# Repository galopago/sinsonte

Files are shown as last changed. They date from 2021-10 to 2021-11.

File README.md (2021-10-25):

# SOUND PLAYER BASED ON RPI PICO

Sound player based on Raspberry Rpi Pico. Sound data are stored in onboard memory. Very few external (easy to find & solder) components required. The project was designed to be in sleep mode for a very long time powered by batteries. Can be used for musical wall clocks, talking dolls, toys, etc.

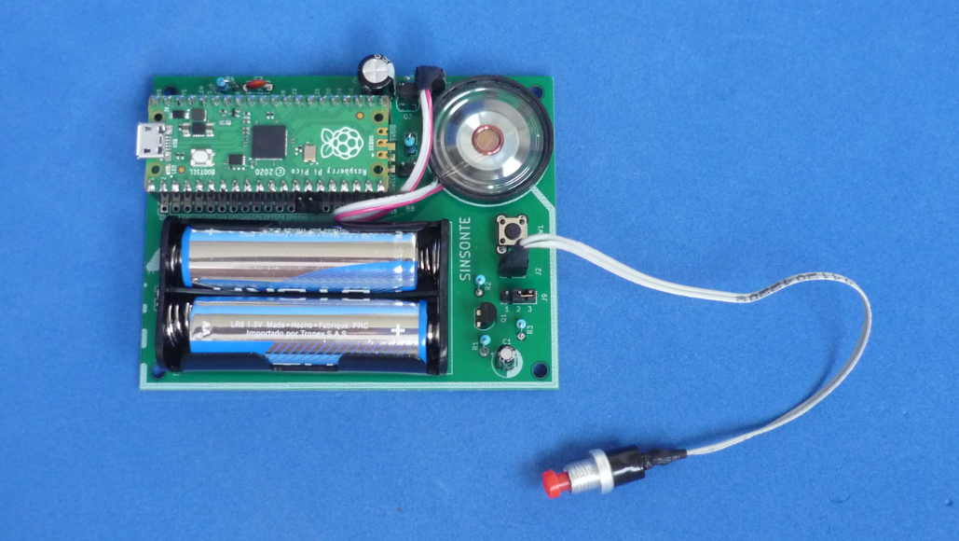
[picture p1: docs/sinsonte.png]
BOARD


Printed circuit board with all components soldered.

Also read this in other languages: [Espanol](/docs/README.es.md)

## Working principle

The circuit ([see schematic](/docs/schematic.pdf)) has been designed to stay most of the time in silence powered by 2 AA batteries, like musical wall clocks or talking toys. In the best scenario, Rpi Pico in in deep sleep mode, will drain approx 1.3 mAh from the batteries. A pair of AA batteries in series have around 2000 mAh of juice, just in standby they will last only for two months. Unacceptable!.

An external circuit was added to totally power off Rpi Pico via 3V3_EN pin. Draining just only 70 uAh, which translates to 3 years of standby. Much better!

The circuit work in the following manner: In standby mode, a capacitor with a large resistor holds the conduction voltage of a MOSFET which is in charge of tying 3V3_EN to ground, powering off the board completely. To play a sound, click briefly on the push button which discharges the capacitor and stops conduction of the MOSFET. Now 3V3_EN pin is tied to V+ via its internal pull up, powering on the Rpi Pico Board. Once powered on and program booted, it keeps the capacitor discharged via a GPIO while sound is played. When the sound ends, the RPI Pico puts the GPIO in high impedance state, so the capacitor charges again and Rpi Powers off until the next click on the button!

There are many stored sounds in the Rpi Pico, and they are played in sequence. To know which sound needs to be played in the next click, some data needs to be preserved between power offs, that data is stored in the internal flash memory. Be careful modifying the program to keep flash writes to a minimum.

The program was written using the Rpi Pico SDK and more or less the same functionality also in CircuitPython too!

## Directory structure

Hardware folder contains schematic and printed circuit board.
* /hardware/ folder contains KiCad V5.1 project
* /hardware/gerber folder contains ready to manufacture files.
* /hardware/modules folder contains additional footprints needed to edit printed circuit board.
* /hardware/library folder contains additional symbols needed to edit schematic.

Software folder contains program source code.
* /software/sdk folder contains C source code for multiple apps develped with the Raspberry **Pi Pico SDK**.
* /software/sdk/clock/build folder will contain downloadable binaries once compiled.
* /software/sdk/_utils folder contain additional python scripts.
* /software/sdk/_uf2_binaries folder contains compiled programs ready for download to the Rpi Pico.
* /software/sdk/_sounds folder contains sound files source in form of C arrays[].

* /software/cp folder contains Python source code for multiple apps develped with **CircuitPython**.
* /software/cp/_sounds folder contains sound files source in .mp3 format
* /software/cp/_utils folder contains contains binary files

Docs folder contains additional info files

# C/C++ SDK
## How to use this repository

This is a very brief guide how to install Rpi Pico SDK on Linux (Ubuntu!). For more info please visit [official repo](https://github.com/raspberrypi/pico-sdk)
~~~
sudo apt install cmake gcc-arm-none-eabi libnewlib-arm-none-eabi build-essential
git clone -b master https://github.com/raspberrypi/pico-sdk.git
cd pico-sdk
git submodule update --init
~~~
Add the line below to .bashrc file, and then restart session to allow changes to take effect.
~~~
export PICO_SDK_PATH={sdk path}/pico-sdk
~~~
Clone project repository
~~~
git clone https://github.com/galopago/SINSONTE.git
~~~
* Modify /SINSONTE/software/sdk/clock/CMakeLists.txt file change Rpi Pico SDK paths with your own installation paths.
* Delete /SINSONTE/software/sdk/clock/build/CMakeCache.txt file
* Delete /SINSONTE/software/sdk/clock/build/elf2uf2/CMakeCache.txt file

Using the command line terminal go to the folder /SINSONTE/software/sdk/clock/build
~~~
cd software/sdk/clock/build
~~~
Generate makefiles
~~~
cmake ..
~~~
And finally compile:
~~~
make clean
make all
~~~
(.uf2) downloadable compiled file lies in /SINSONTE/software/sdk/clock/build

## How to change sound files

The sample program shown here, plays 12 different sound files sequentially. If you want to change one or all of them, the following rules must be taken into account:

* Max sound storage capacity is 24 seconds total (~2 seconds per file * 12 files = ~24 seconds)
* Sound files have to be in .WAV mono 16 bit @ 44100 hz before being processed by the script which converts them into C array[]

Look for **wav2c.py** script in /SINSONTE/software/sdk/_utils/ folder to convert your own sounds.

This script need two parameters: input sound file name (.wav) and output file name (.h). The files have to be named 1.h to 12.h. Here is an example:

~~~
python3 wav2c.py example.wav 5.h
~~~

The generated file (5.h) needs to be put in /SINSONTE/software/sdk/clock folder and then recompile!

# CircuitPython
## How to use this repository
Clone project repository
~~~
git clone https://github.com/galopago/SINSONTE.git
~~~
* Put Rpi Pico in programming mode and then plug into a PC
* To start fresh, download to the Rpi Pico the file **flash_nuke.uf2** located in /SINSONTE/software/cp/_utils
* Put Rpi Pico in programming mode again and then plug into a PC
* Install CircuitPython runtime downloading the file **adafruit-circuitpython-raspberry_pi_pico-en_US-6.3.0.uf2** located in /SINSONTE/software/cp/_utils
* Once CircuitPython is installed, download to the Rpi Pico **code.py** and the sound files (1.mp3 to 12.mp3) located in /SINSONTE/software/cp/clock folder

## How to change sound files
Download to the Rpi Pico your own .mp3 file, it needs to be named 1.mp3 to 12.mp3

## License
This is an Open Source project and is licensed under [MIT License](https://spdx.org/licenses/MIT.html)

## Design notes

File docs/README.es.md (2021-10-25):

# REPRODUCTOR DE SONIDO BASADO EN RPI PICO

Reproductor de sonido basado en Raspberry Rpi Pico. Almacena los datos de sonido en la memoria interna. Requiere muy pocos componentes externos faciles de conseguir y de ensamblar. Fue diseñado con el objetivo de permanecer en modo espera durante muy largo tiempo alimentado por baterias. Puede usarse en relojes de pared musicales, como voz para alguna muñeca o juguete, etc.

TARJETA

Tarjeta de circuito impreso con todos los componentes montados.

Tambien puede leer esto otros idiomas: [English](../README.md)

## Funcionamiento general

El circuito ([ver esquematico](../docs/schematic.pdf)) se ha diseñado para que permanezca la mayoria del tiempo en silencio y alimentado por 2 baterias AA, como es el caso de los relojes musicales o juguetes que hablan. En el mejor de los casos, el Rpi Pico en su menor consumo (usando funciones de sueño profundo), drenara aproximadamente 1.3 mAh de las baterias. Como un par de baterias AA tiene una capacidad aproximada de 2000 mAh, solamente en modo espera tendrian una duracion aproximada de dos meses. Inaceptable!.

Se adiciono un circuito externo que mantiene totalmente apagado el Rpi Pico usando el pin 3V3_EN de esta forma solo consumira aproximadamente unos 70 uA, lo que se traduce en unos 3 años en modo espera. Mucho mejor!

El sistema funciona de la siguiente manera: En modo reposo, un condensador mediante una resistencia grande mantienen el voltaje de conduccion de un mosfet que es el encargado de poner a tierra la señal 3V3_EN, apagando totalmente la tarjeta. Para reproducir un sonido se debera pulsar brevemente un interruptor. Este interruptor descarga el condensador rapidamente, apagando el mosfet y haciendo que la señal 3V3_EN quede a V+ mediante su resistencia interna, haciendo que el Rpi Pico se encienda. Una vez encendido el Rpi Pico, este mantiene descargado el condensador mediante un GPIO durante la reproduccion del sonido. Al finalizar la reproduccion, el GPIO se pone en alta impedancia haciendo que el circuito externo cargue de nuevo el condensador y apague el Rpi Pico hasta la proxima pulsacion!

En el Rpi Pico se almacenan varios sonidos, y estos se reproducen en secuencia con cada pulsacion del interruptor. Para poder guardar cual sonido se repoducira en la siguiente pulsacion, se hace uso de la memoria flash interna, por lo que se debera analizar con cuidado la aplicacion final del circuito para evitar desgastes rapidos de la flash.

El programa fue escrito usando el Rpi Pico SDK y se porto mas o menos la misma funcionalidad a CircuitPython tambien!

## Estructura de directorios

El directorio hardware contiene el esquematico y circuito impreso.
* El directorio /hardware/ contiene el proyecto completo en KiCad V5.1.
* El directorio /hardware/gerber contiene los archivos de fabricacion del circuito impreso.
* El directorio /hardware/modules contiene footprints adicionales necesarios para poder editar el circuito impreso.
* El directorio /hardware/library contiene simbolos adicionales necesarios para poder editar el esquematico.

El directorio software contiene el codigo fuente del programa.
* El directorio /software/sdk contiene el codigo fuente en C de varias apps desarrolladas en el **Raspberry Pi Pico SDK**.
* El directorio /software/sdk/clock/build contendra los archivos cuando se compila el codigo.
* El directorio /software/sdk/_utils contiene scripts complementarios en python.
* El directorio /software/sdk/_uf2_binaries contiene archivos compilados listos para descargar al Rpi Pico.
* El directorio /software/sdk/_sounds contiene archivos de sonido en forma de arrays[] de C.

* El directorio /software/cp contiene el codigo fuente de en Python de varias apps desarrolladas en el **CircuitPython**.
* El directorio /software/cp/_sounds contiene archivos de sonido en formato mp3.
* El directorio /software/cp/_utils contiene archivos binarios.

El directorio docs contiene archivos adicionales

# C/C++ SDK
## Como usar este repositorio

Esta es una descripcion breve de como instalar el Rpi Pico SDK en Linux (Ubuntu!). Para mayor informacion ir al [repo oficial](https://github.com/raspberrypi/pico-sdk)
~~~
sudo apt install cmake gcc-arm-none-eabi libnewlib-arm-none-eabi build-essential
git clone -b master https://github.com/raspberrypi/pico-sdk.git
cd pico-sdk
git submodule update --init
~~~
Se debera añadir la siguiente linea al archivo .bashrc y despues de hacerlo, reiniciar sesion para que tome efecto
~~~
export PICO_SDK_PATH={ruta sdk}/pico-sdk
~~~
Clonar el repositorio del proyecto
~~~
git clone https://github.com/galopago/SINSONTE.git
~~~
* Modificar el archivo /SINSONTE/software/sdk/clock/CMakeLists.txt cambiando las rutas del SDK Pico por la ruta en que se instalo en su propia computadora.
* Borrar el archivo /SINSONTE/software/sdk/clock/build/CMakeCache.txt
* Borrar el archivo /SINSONTE/software/sdk/clock/build/elf2uf2/CMakeCache.txt

Mediante la interfaz linea de comando acceda al directorio /SINSONTE/software/sdk/clock/build
~~~
cd software/sdk/clock/build
~~~
Crear los makefiles
~~~
cmake ..
~~~
Y finalmente para compilar:
~~~
make clean
make all
~~~
El programa compilado (.uf2) para descargar al Rpi Pico se encontrara en la carpeta /SINSONTE/software/sdk/clock/build

## Como cambiar los archivos de sonido

El programa presentado aqui reproduce 12 diferentes archivos de sonido de forma secuencial. Si se quiere cambiar uno o todos los archivos se debera tener en cuenta lo siguiente:

* La duracion maxima de almacenamiento de la memoria es de 24 segundos (2 segundos por sonido * 12 = 24 segundos)
* Los archivos deberan convertirse a formato .WAV monofonico de 16 bits y a 44100 hz antes de ser procesados por la aplicacion que los convertira en array[] de C.

Una vez se tienen los archivos con las caracteristicas anteriormente mencionadas, se usara la aplicacion **wav2c.py** que se encuentra en la ruta /SINSONTE/software/sdk/_utils

Esta aplicacion recibe dos parameteros: el nombre de arhcivo de entrada (.wav) y nombre de archivo de salida (.h). Los nombres de los archivos convertidos deberan llamarse 1.h a 12.h. Un ejemplo seria el siguiente:

~~~
python3 wav2c.py ejemplo.wav 5.h
~~~

El archivo generado (5.h) debera ponerse en la carpeta /SINSONTE/software/sdk/clock y recompilar el codigo

# CircuitPython
## Como usar este repositorio

Clonar el repositorio del proyecto
~~~
git clone https://github.com/galopago/SINSONTE.git
~~~
* Poner el Rpi Pico en modo programacion y luego conectar a un PC
* Para iniciar con todo limpio, descargar al Rpi Pico el archivo **flash_nuke.uf2** que se encuentra en /SINSONTE/software/cp/_utils
* Poner nuevamente el Rpi Pico en modo programacion y conectar a un PC
* Instalar CircuitPython descargandole el archivo **adafruit-circuitpython-raspberry_pi_pico-en_US-6.3.0.uf2** que se encuentra en /SINSONTE/software/cp/_utils
* Una vez ya se ha instalado CircuitPython, descargar al Rpi Pico el archivo **code.py** y los archivos de sonido (1.mp3 al 12.mp3) que se encuentran en /SINSONTE/software/cp/clock 

## Como cambiar los archivos de sonido
Descargar al Pico sus propios archivos .mp3, estos deben llamarse 1.mp3 al 12.mp3

## Licencia
Este es un proyecto de Software Libre y esta licenciado bajo una licencia [MIT License](https://spdx.org/licenses/MIT.html)

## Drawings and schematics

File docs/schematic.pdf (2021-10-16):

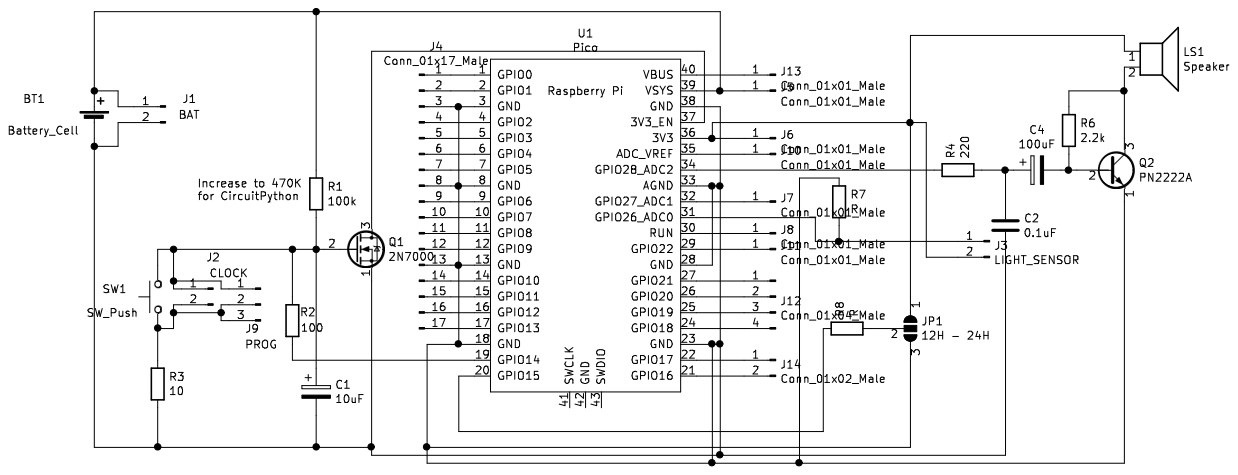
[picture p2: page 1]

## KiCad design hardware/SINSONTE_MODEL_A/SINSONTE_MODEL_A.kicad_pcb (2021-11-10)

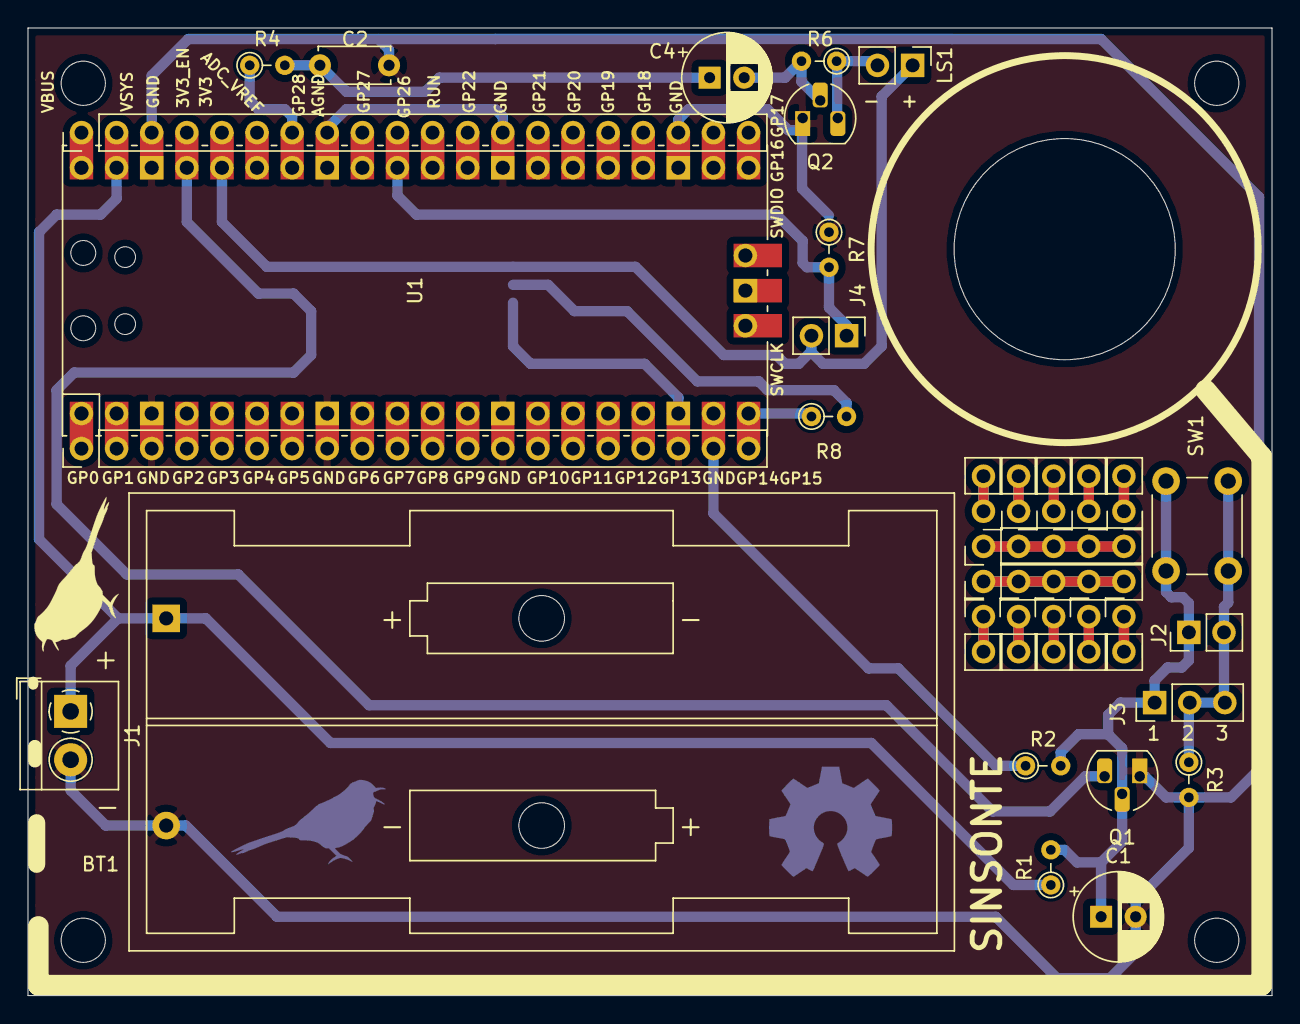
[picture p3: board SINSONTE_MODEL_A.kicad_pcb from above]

Board: 2 copper layers, 90.0 x 70.0 mm, 35 parts (1 on the bottom side), 51 nets.

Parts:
BT1: Battery_Cell; BatteryHolder_Keystone_2462_2xAA
C1: 10uF; CP_Radial_D6.3mm_P2.50mm
C2: 0.1uF; C_Disc_D5.0mm_W2.5mm_P5.00mm
C4: 100uF; CP_Radial_D6.3mm_P2.50mm
J1: BAT; TerminalBlock_4Ucon_1x02_P3.50mm_Horizontal
J2: CLOCK; PinHeader_1x02_P2.54mm_Vertical
J3: PROG; PinHeader_1x03_P2.54mm_Vertical
J4: LIGHT_SENSOR; PinHeader_1x02_P2.54mm_Vertical
J5, J6: Conn_01x20_Male; PinHeader_1x20_P2.54mm_Vertical
J7, J8: Conn_01x05_Male; PinHeader_1x05_P2.54mm_Vertical
J9, J10, J11, J12, J13, J14, J15, J16, J17, J18: Conn_01x02_Male; PinHeader_1x02_P2.54mm_Vertical
JP1: 12H - 24H; SolderJumper-3_P1.3mm_Open_RoundedPad1.0x1.5mm_NumberLabels
LS1: Speaker; PinHeader_1x02_P2.54mm_Vertical
Q1: 2N7000; TO-92_HandSolder
Q2: PN2222A; TO-92_HandSolder
R1: 100k; R_Axial_DIN0204_L3.6mm_D1.6mm_P2.54mm_Vertical
R2: 100; R_Axial_DIN0204_L3.6mm_D1.6mm_P2.54mm_Vertical
R3: 10; R_Axial_DIN0204_L3.6mm_D1.6mm_P2.54mm_Vertical
R4: 220; R_Axial_DIN0204_L3.6mm_D1.6mm_P2.54mm_Vertical
R6: 2.2k; R_Axial_DIN0204_L3.6mm_D1.6mm_P2.54mm_Vertical
R7, R8: R; R_Axial_DIN0204_L3.6mm_D1.6mm_P2.54mm_Vertical
SW1: SW_Push; SW_PUSH_6mm_H4.3mm
U1: Pico; RPi_Pico_SMD_TH

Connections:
unnamed: BT1.1, J1.1, J6.2, R1.1, U1.39
unnamed: BT1.2, C1.2, C2.2, J1.2, J5.3, J5.8, J5.13, J5.18, J6.3, J6.8, J6.13, J6.18, JP1.3, Q1.1, Q2.1, R3.2, R7.1, U1.3, U1.8, U1.13, U1.18, U1.23, U1.28, U1.33, U1.38
unnamed: C1.1, J2.1, J3.1, Q1.2, R1.2, R2.2, SW1.1
unnamed: C2.1, C4.1, R4.2
unnamed: C4.2, Q2.2, R6.2
unnamed: J2.2, J3.2, J3.3, R3.1, SW1.2
unnamed: J4.1, J6.10, R7.2, U1.31
unnamed: J4.2, J6.5, JP1.1, LS1.1, U1.36
unnamed: J5.1, U1.1
unnamed: J5.2, U1.2
unnamed: J5.4, U1.4
unnamed: J5.5, U1.5
unnamed: J5.6, U1.6
unnamed: J5.7, U1.7
unnamed: J5.9, U1.9
unnamed: J5.10, U1.10
unnamed: J5.11, U1.11
unnamed: J5.12, U1.12
unnamed: J5.14, U1.14
unnamed: J5.15, U1.15
unnamed: J5.16, U1.16
unnamed: J5.17, U1.17
unnamed: J5.19, R2.1, U1.19
unnamed: J5.20, R8.1, U1.20
unnamed: J6.1, U1.40
unnamed: J6.4, Q1.3, U1.37
unnamed: J6.6, U1.35
unnamed: J6.7, R4.1, U1.34
unnamed: J6.9, U1.32
unnamed: J6.11, U1.30
unnamed: J6.12, U1.29
unnamed: J6.14, U1.27
unnamed: J6.15, U1.26
unnamed: J6.16, U1.25
unnamed: J6.17, U1.24
unnamed: J6.19, U1.22
unnamed: J6.20, U1.21
unnamed: J7.1, J7.2, J7.3, J7.4, J7.5
unnamed: J8.1, J8.2, J8.3, J8.4, J8.5
unnamed: J9.1, J9.2
unnamed: J10.1, J10.2
unnamed: J11.1, J11.2
unnamed: J12.1, J12.2
unnamed: J13.1, J13.2
unnamed: J14.1, J14.2
unnamed: J15.1, J15.2
unnamed: J16.1, J16.2
unnamed: J17.1, J17.2
unnamed: J18.1, J18.2
unnamed: JP1.2, R8.2
unnamed: LS1.2, Q2.3, R6.1

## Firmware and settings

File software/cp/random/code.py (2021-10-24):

"""
***************************************************************************************
MP3 audio player based on Rpi Pico
audio data is stored in onboard flash filesystem Up to 800 KB of sound capacity
plays one clip of sound (random) on every power on
and uses external circuit for very low power 
***************************************************************************************
"""
import board
import digitalio
import analogio
import audiomp3
import audiopwmio
import os
import pwmio
import microcontroller
import random

"""
*****************************************************
TEPT5700 sensor with 10K resistor aprox ADC readings
*****************************************************
LUX(MS6610)    RAW		    VOLT

  48			0x0a8		0.135352
  33			0x070		0.090234
  21			0x054		0.067676
  14			0x03b		0.047534
   7			0x033		0.041089
   6			0x029		0.033032
   5			0x031		0.039478
   4			0x026		0.030615
"""
light_sensor_threshold = 0.030615 
analog_gpio = board.GP26_A0
poweroff_gpio = board.GP14
audio_gpio = board.GP28_A2
ext_led_gpio = board.GP10
default_next_hour = 1
night_time = 0
NUMBER_OF_FILES=12

# Do this ASAP! to keep board powered on

poweroff = digitalio.DigitalInOut(poweroff_gpio)
poweroff.direction = digitalio.Direction.OUTPUT
poweroff.value = False

led = digitalio.DigitalInOut(board.LED)
led.direction = digitalio.Direction.OUTPUT
led.value = True

light_sensor = analogio.AnalogIn(analog_gpio)
audio = audiopwmio.PWMAudioOut(audio_gpio)

#Generating random number to know which file to play
internal_adc_value=microcontroller.cpu.temperature
float_adc_value = 10000 * internal_adc_value
int_adc_value = int(float_adc_value)

random.seed(int_adc_value)
random_number=random.randint(1,NUMBER_OF_FILES)
print("float adc",float_adc_value)
print("int adc",int_adc_value)
print("random number",random_number)
next_hour=random_number;
	
# Check light sensor to know if it's night time
raw_adc = light_sensor.value
light_voltage = ( raw_adc / 65535	) * light_sensor.reference_voltage
print("raw adc",raw_adc)
print("light voltage",light_voltage)

if light_voltage < light_sensor_threshold :
	night_time = 1
	print("it's nightime!")
else :	
	night_time = 0
	print("it's daytime!")
	
if next_hour == 1 :
	print("playing sound 1")
	decoder = audiomp3.MP3Decoder(open("1.mp3", "rb"))

if next_hour == 2 :
	print("playing sound 2")
	decoder = audiomp3.MP3Decoder(open("2.mp3", "rb"))

if next_hour == 3 :
	print("playing sound 3")
	decoder = audiomp3.MP3Decoder(open("3.mp3", "rb"))

if next_hour == 4 :
	print("playing sound 4")
	decoder = audiomp3.MP3Decoder(open("4.mp3", "rb"))

if next_hour == 5 :
	print("playing sound 5")
	decoder = audiomp3.MP3Decoder(open("5.mp3", "rb"))

if next_hour == 6 :
	print("playing sound 6")
	decoder = audiomp3.MP3Decoder(open("6.mp3", "rb"))

if next_hour == 7 :
	print("playing sound 7")
	decoder = audiomp3.MP3Decoder(open("7.mp3", "rb"))

if next_hour == 8 :
	print("playing sound 8")
	decoder = audiomp3.MP3Decoder(open("8.mp3", "rb"))

if next_hour == 9 :
	print("playing sound 9")
	decoder = audiomp3.MP3Decoder(open("9.mp3", "rb"))

if next_hour == 10 :
	print("playing sound 10")
	decoder = audiomp3.MP3Decoder(open("10.mp3", "rb"))

if next_hour == 11 :
	print("playing sound 11")
	decoder = audiomp3.MP3Decoder(open("11.mp3", "rb"))

if next_hour == 12 :
	print("playing sound 12")
	decoder = audiomp3.MP3Decoder(open("12.mp3", "rb"))

#Only play sounds on DayLight

blink_led=pwmio.PWMOut(ext_led_gpio,duty_cycle=50,frequency=1,variable_frequency=False)	
if 	night_time == 0 :
	audio.play(decoder)

while audio.playing:
    pass

print("Done playing!")

blink_led.duty_cycle=0
led.value = False

poweroff.value = True
poweroff.direction = digitalio.Direction.INPUT

#Just stop here
while True:
    pass

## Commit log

2021-03-08 power on/off elements added
    [SINSONTE.kicad_pcb, SINSONTE.sch]
2021-03-08 core components added
    [SINSONTE.kicad_pcb, SINSONTE.sch]
2021-03-09 updated features elements added
    [SINSONTE.kicad_pcb, SINSONTE.sch]
2021-03-10 90% routed
    [SINSONTE.kicad_pcb, SINSONTE.sch]
2021-03-10 all traces routed
    [SINSONTE.kicad_pcb, SINSONTE.sch]
2021-03-11 sw project cleaned
    [pico_configs.tsv]
2021-03-12 resistor removed
    [SINSONTE.kicad_pcb, SINSONTE.sch]
2021-03-13 expansion headers
    [SINSONTE.kicad_pcb, SINSONTE.sch]
2021-03-14 changed autopower off strategy
    [SINSONTE.kicad_pcb, SINSONTE.sch]
2021-03-14 mounting holes
    [SINSONTE.kicad_pcb]
2021-03-14 all expansion headers placed
    [SINSONTE.kicad_pcb, SINSONTE.sch]
2021-03-14 copper ground plane, need some checks
    [SINSONTE.kicad_pcb, SINSONTE.sch]
2021-03-15 changed transistors footprint for handsolder
    [SINSONTE-B_Cu.gbr, SINSONTE-B_Mask.gbr, SINSONTE-B_Paste.gbr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]
2021-03-16 updated gerbers
    [SINSONTE-B_Cu.gbr, SINSONTE-B_Mask.gbr, SINSONTE-B_Paste.gbr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]
2021-03-18 trace a bit away from edge
    [SINSONTE.kicad_pcb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]
2021-03-18 program jumper trace minor update
    [SINSONTE.kicad_pcb, SINSONTE.sch]
2021-04-19 moved speaker a bit and cleaned some refs silks
    [SINSONTE.kicad_pcb]
2021-04-19 some pcb decorations
    [SINSONTE.kicad_pcb]
2021-04-20 top silks finished
    [SINSONTE.kicad_pcb]
2021-04-21 all silks finished
    [SINSONTE.kicad_pcb]
2021-04-22 gerbers generated
    [SINSONTE-B_Cu.gbr, SINSONTE-B_Mask.gbr, SINSONTE-B_Paste.gbr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]
2021-04-26 cu plane added front
    [SINSONTE-B_Cu.gbr, SINSONTE-B_Mask.gbr, SINSONTE-B_SilkS.gbr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]
2021-06-04 compontent values sch added
    [SINSONTE.sch]
2021-06-04 capacitor fixed polarity
    [SINSONTE-B_Cu.gbr, SINSONTE-B_Mask.gbr, SINSONTE-B_SilkS.gbr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]
2021-08-15 changed light sensor resistor to pull-down
    [SINSONTE.kicad_pcb, SINSONTE.sch]
2021-08-15 updated gerbers light sensor
    [SINSONTE-B_Cu.gbr, SINSONTE-B_Mask.gbr, SINSONTE-B_SilkS.gbr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]
2021-08-16 light sensor code added
2021-10-11 debunging uart adc
2021-10-11 lux sensor data table added
2021-10-12 added external led output
2021-10-13 some info added
    [SINSONTE.kicad_pcb, SINSONTE.sch]
2021-10-16 add note to change R1 for CP
    [SINSONTE.sch]
2021-10-17 light sensor added
2021-10-17 ext led gpio10 added
2021-10-17 ext led gpio10 added sdk
2021-11-09 changed ext batt for screw terminal type
    [SINSONTE.kicad_pcb, SINSONTE.sch]
2021-11-09 rpi first half conn aded 1 pos on ground
    [SINSONTE.kicad_pcb, SINSONTE.sch]
2021-11-09 rpi first half conn aded all pins connector
    [SINSONTE.kicad_pcb, SINSONTE.sch]
2021-11-09 rpi second half conn aded all pins connector
    [SINSONTE.kicad_pcb, SINSONTE.sch]
2021-11-10 added proto area
    [SINSONTE.kicad_pcb, SINSONTE.sch]
2021-11-10 minor adjustments
    [SINSONTE.kicad_pcb, SINSONTE.sch]
2021-11-10 gerber files generated
    [SINSONTE-B_Cu.gbr, SINSONTE-B_Mask.gbr, SINSONTE-B_SilkS.gbr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]
2021-11-10 created model A variant
    [SINSONTE_MODEL_A-B_Cu.gbr, SINSONTE_MODEL_A-B_Mask.gbr, SINSONTE_MODEL_A-B_SilkS.gbr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]
2021-11-10 created model B variant
    [SINSONTE-B_Cu.gbr, SINSONTE-B_Mask.gbr, SINSONTE-B_SilkS.gbr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]
2021-11-10 deleted initial first project before variants
    [SINSONTE-B_Cu.gbr, SINSONTE-B_Mask.gbr, SINSONTE-B_SilkS.gbr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]
2021-11-10 shrinkikng in process
    [SINSONTE_MODEL_B.kicad_pcb, SINSONTE_MODEL_B.sch]
2021-11-10 shrinkikng finished
    [SINSONTE_MODEL_B.kicad_pcb, SINSONTE_MODEL_B.sch]
2021-11-10 single gerber
    [SINSONTE-B_Cu.gbr, SINSONTE-B_Mask.gbr, SINSONTE-B_SilkS.gbr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]
2021-11-10 single gerber proto fix
    [SINSONTE_MODEL_B-B_Cu.gbr, SINSONTE_MODEL_B-B_Mask.gbr, SINSONTE_MODEL_B-B_SilkS.gbr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]
2021-11-10 panel gerber proto fix
    [SINSONTE_MODEL_B_PANEL-B_Cu.gbr, SINSONTE_MODEL_B_PANEL-B_Mask.gbr, SINSONTE_MODEL_B_PANEL-B_SilkS.gbr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]
2021-11-10 small gpio silk fix
    [SINSONTE_MODEL_A-B_Cu.gbr, SINSONTE_MODEL_A-B_Mask.gbr, SINSONTE_MODEL_A-B_SilkS.gbr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]
